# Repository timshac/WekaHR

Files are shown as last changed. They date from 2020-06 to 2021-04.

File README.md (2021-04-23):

# WekaHR modbus slave holding registers synchronised with google sheets

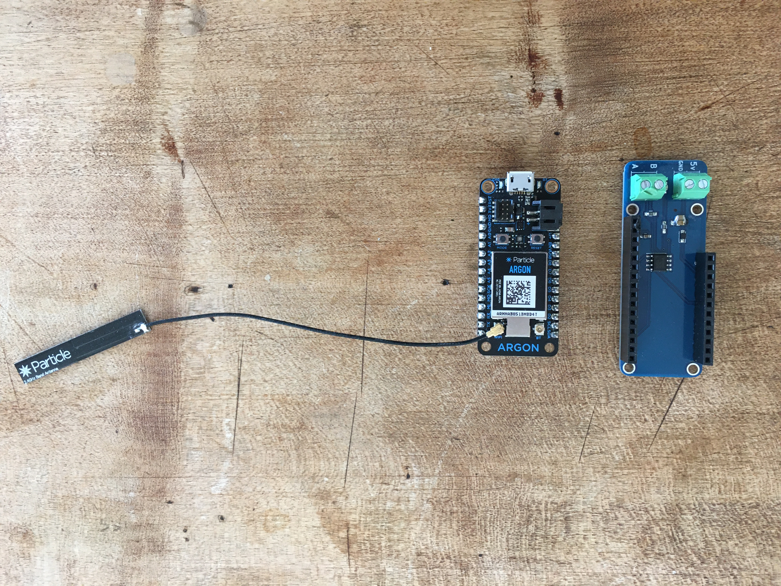
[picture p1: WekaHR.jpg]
WekaHR


The WekaHR is a modbus slave (RS-485) with read/write registers that are synced with your google sheet. Your PLC can connect to the WekaHR modbus slave to read and write register values to report data or configure PLC operations.

## Components

* WekaHR featherwing
* a PLC (supplied by you)
* Particle Argon (Wifi) or Boron (cellular) IOT device
* Google Sheet Application

## Connect hardware

1. Wire the WekaHR to your PLC.  The WekaHR is powered by 5v DC. Schnieder PLCs provide 5v via the modbus port
2. Insert the Boron or Argon into the WekaHR
3. Connnect particle Boron or Argon to the particle cloud, and give the device a name (deviceName)

Then you are ready to flash the firmware

## Flash Firmware

Clone this repository, and install the [particle command line tools](https://docs.particle.io/tutorials/developer-tools/cli/)

```
cd WekaHR/firmware/particle_gen3
# compile and flash over WiFi or Cellular
particle flash deviceName 

# or, for usb connected particle
particle compile argon|boron --saveTo=bin
particle serial list
particle serial flash bin
```

## Initial WekaHR module setup, for a fresh new module

Issue these commands to in the particle console (console.particle.io). The modbus baud is set in the code, currently to 19200 8N1
```
SetUnitID 10   # to set modbus slave ID (defaults to 10)
SetEventName "companyname/projectname"   # set the particle webhook event name

```

## Save a copy of the linked google sheet

Save a copy of this [WekaHR Google Sheets Template](https://docs.google.com/spreadsheets/d/1dsoAosavrSCt88q0tjWTA6WfT7lwxBgexuUGqGGjWAQ/copy?usp=sharing) and follow the instructions in the worksheet to connect your particle to the google sheet using a webhook.

## Connect particle cloud to google sheet

Follow the instructions in the google sheet to connect your particle device to the google sheeet using a particle webhook integration.

## Particle API - Functions

#### int ManualUpdate(String args = "")

Trigger a manual JSON packet publish and JSON settings register response.  Running this function ensures that application register values are set in the WekaHR.

#### int PublishUnitID(String args = "")

Publish the current modbus id. Defaults to 10.

#### int SetUnitID(String args = "number 1-247")

Set the device modbus id.

#### int PublishEventName(String args = "")

Publish the current event name.

#### int SetEventName(String args = "eventName")

Set the current event name.  Suggested format is CompanyName/ProjectName, where multiple customer sites may share the same CompanyName and ProjectName.

#### int PublishSettingsJSON(String args)

Publish the current JSON settings saved to EEPROM.  

#### int SetSettingsJSON(String args)

Save string args as current JSON settings to EEPROM.  Use with caution.

## JSON Published to Google Sheet

```
JSON:
{
  "name": "companyname/dairyshed",
  "data": "{\"v\":\"1.0\",\"func\":\"writeLog\",\"addr\":0,\"HR\":[0,0,0,0,0,0,0,0,0,0,0,0,0,0,0,0,0,0,2048,0,0,0,0,0,0,0,0,0,0,0,0,0,0,0,0,0,0,0,0,0,0,0,0,0,0,0,0,0,0,0,0,0,0,0,0,0,0,0,0,0,0,0,0,0,0,0,0,0,0,0,0,0,0,0,0,0,0,0,0,0]}",
  "ttl": 60,
  "published_at": "2019-10-20T01:54:46.580Z",
  "coreid": "coreid"
}

the data key, when interpreted as JSON:
{"v":"1.0","func":"writeLog","addr":0,"HR":[0,0,0,0,0,0,0,0,0,0,0,0,0,0,0,0,0,0,2048,0,0,0,0,0,0,0,0,0,0,0,0,0,0,0,0,0,0,0,0,0,0,0,0,0,0,0,0,0,0,0,0,0,0,0,0,0,0,0,0,0,0,0,0,0,0,0,0,0,0,0,0,0,0,0,0,0,0,0,0,0]}

```

Version "v" key, "v" = "1.0", where 1.0 could be anything < 2.0.  (eg 1.1,1.2, etc)
The holding registers are given as an array, starting at address "addr".
HR = [javascript array].  The current length of the array is 80 [registers addr + 0 to addr + 79], but could be anything from length 1-100.

The WekaHR accepts a JSON response that sets HR values.  The response looks like:

```

{"40":1,"41":2,"42":3,"43":0,"44":0,"45":0,"46":0,"47":0,"48":0,"49":0,"50":0,"51":0,"52":0,"53":0,"54":0,"55":0,"56":0,"57":0,"58":0,"59":0,"60":0,"61":0,"62":0,"63":0,"64":0,"65":0,"66":0,"67":0,"68":0,"69":0,"70":0,"71":0,"72":0,"73":0,"74":0,"75":0,"76":0,"77":0,"78":0,"79":12,"sheet":"https://docs.google.com/a/xxx.xxx.xxx/spreadsheets/d/yyyyyyyyyyyyyyyyyyyyyyyyyyyyyyyyyyyyyyyy/edit","row":38}

```

This includes registers set and their numeric value to be set, as well as the source google sheet or application url.

## Licenses

* Hardware: CERN-OHL-P
* Firmware: MIT
* Documentation: MIT

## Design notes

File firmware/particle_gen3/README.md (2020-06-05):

# WekaHR

 WekaHR Firmware

## Flash Firmware

This firmware can be used on a Particle.io Argon (wifi) or Boron (cellular) internet device.

Clone this repository, and install the [particle command line tools](https://docs.particle.io/tutorials/developer-tools/cli/)

```
cd WekaHR/firmware/particle_gen3
# compile and flash over WiFi or Cellular
particle flash deviceName 

# or, for usb connected particle
particle compile argon|boron --saveTo=bin
particle serial list
particle serial flash bin
```

## Save a copy of the linked google sheet

Save a copy of this [WekaHR Template](https://docs.google.com/spreadsheets/d/1dsoAosavrSCt88q0tjWTA6WfT7lwxBgexuUGqGGjWAQ/copy?usp=sharing) and follow the instructions in the worksheet to connect your particle to the google sheet using a webhook.

## API

### Functions

Call functions or read variables from the website front-end.  All functions take a string command argument and return an integer result.

Every time the WekaHR recieves an holding register (HR) write from the serial modbus, it publishes a JSON packet, and optionally accepts a JSON response from the application (google sheet) that will update any register values.

Modbus holdingh register reads read from Holding Registers on the slave device, and do not trigger a publish/response from the internet.

### Published Data

```
JSON:
{
  "name": "companyname/dairyshed",
  "data": "{\"v\":\"1.0\",\"func\":\"writeLog\",\"addr\":0,\"HR\":[0,0,0,0,0,0,0,0,0,0,0,0,0,0,0,0,0,0,2048,0,0,0,0,0,0,0,0,0,0,0,0,0,0,0,0,0,0,0,0,0,0,0,0,0,0,0,0,0,0,0,0,0,0,0,0,0,0,0,0,0,0,0,0,0,0,0,0,0,0,0,0,0,0,0,0,0,0,0,0,0]}",
  "ttl": 60,
  "published_at": "2019-10-20T01:54:46.580Z",
  "coreid": "coreid"
}

the data key, when interpreted as JSON:
{"v":"1.0","func":"writeLog","addr":0,"HR":[0,0,0,0,0,0,0,0,0,0,0,0,0,0,0,0,0,0,2048,0,0,0,0,0,0,0,0,0,0,0,0,0,0,0,0,0,0,0,0,0,0,0,0,0,0,0,0,0,0,0,0,0,0,0,0,0,0,0,0,0,0,0,0,0,0,0,0,0,0,0,0,0,0,0,0,0,0,0,0,0]}

```

Version "v" key, "v" = "1.0", where 1.0 could be anything < 2.0.  (eg 1.1,1.2, etc)
The holding registers are given as an array, starting at address "addr".
HR = [javascript array].  The current length of the array is 80 [registers addr + 0 to addr + 79], but could be anything from length 1-100.

The WekaHR accepts a JSON response that sets HR values.  The response looks like:

```

{"40":1,"41":2,"42":3,"43":0,"44":0,"45":0,"46":0,"47":0,"48":0,"49":0,"50":0,"51":0,"52":0,"53":0,"54":0,"55":0,"56":0,"57":0,"58":0,"59":0,"60":0,"61":0,"62":0,"63":0,"64":0,"65":0,"66":0,"67":0,"68":0,"69":0,"70":0,"71":0,"72":0,"73":0,"74":0,"75":0,"76":0,"77":0,"78":0,"79":12,"sheet":"https://docs.google.com/a/xxx.xxx.xxx/spreadsheets/d/yyyyyyyyyyyyyyyyyyyyyyyyyyyyyyyyyyyyyyyy/edit","row":38}

```

This includes registers set and their numeric value to be set, as well as the source google sheet or application url.

#### int ManualUpdate(String args = "")

Trigger a manual JSON packet publish and JSON settings register response.  Running this function ensures that application register values are set in the WekaHR.

#### int PublishUnitID(String args = "")

Publish the current modbus id. Defaults to 10.

#### int SetUnitID(String args = "number 1-247")

Set the device modbus id.

#### int PublishEventName(String args = "")

Publish the current event name.

#### int SetEventName(String args = "eventName")

Set the current event name.  Suggested format is CompanyName/ProjectName, where multiple customer sites may share the same CompanyName and ProjectName.

#### int PublishSettingsJSON(String args)

Publish the current JSON settings saved to EEPROM.  

#### int SetSettingsJSON(String args)

Save string args as current JSON settings to EEPROM.  Use with caution.

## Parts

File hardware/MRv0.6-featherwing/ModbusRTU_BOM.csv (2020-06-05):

Designator | MPN | Qty | Link
C1 | 0603B104K500NT | 1 | http://file.elecfans.com/web1/M00/7D/4D/o4YBAFwKKSOANZPCAA-X9Qix-h8480.pdf
C2 | CC0805KKX7R7BB106 | 1 | http://file.elecfans.com/web1/M00/65/A6/o4YBAFutoDWASZLJAA4wbrUogSs161.pdf
D1 | B0520WS-7-F | 1 | https://www.digikey.com/product-detail/en/diodes-incorporated/B0520WS-7-F/B0520WS-FDICT-ND/775881
D2 | ORH-YG36A | 1 | http://file.elecfans.com/web1/M00/87/3D/o4YBAFyCSiSATmSOAAZl20WJkbM116.pdf?filename=1536306275544842763.pdf
R1 | AC0603FR-07330RL | 1 | http://file.elecfans.com/web1/M00/81/15/o4YBAFwusm-AS-NzAA6jWBLJWvI829.pdf?filename=AC-series_Yageo.pdf
R2 | RC0603FR-07220RL | 1 | http://file.elecfans.com/web1/M00/9E/C4/pIYBAF053ayARjz1AAYrMQV5Kx0650.pdf
U2 | SP3485CN-L | 1 | https://www.digikey.com/product-detail/en/maxlinear-inc/SP3485CN-L/1016-1144-5-ND/2411076
J1, J2 | ED500/2DS | 2 | http://file.elecfans.com/web1/M00/9F/3B/pIYBAF1AhXyAEEsEAAqeTaLwtzM475.pdf
J3 | PPPC121LFBN-RC | 1 | https://www.digikey.com/product-detail/en/sullins-connector-solutions/PPTC121LFBN-RC/S6100-ND/807231
J4 | PPPC161LFBN-RC | 1 | https://www.digikey.com/product-detail/en/sullins-connector-solutions/PPTC161LFBN-RC/S7014-ND/810154

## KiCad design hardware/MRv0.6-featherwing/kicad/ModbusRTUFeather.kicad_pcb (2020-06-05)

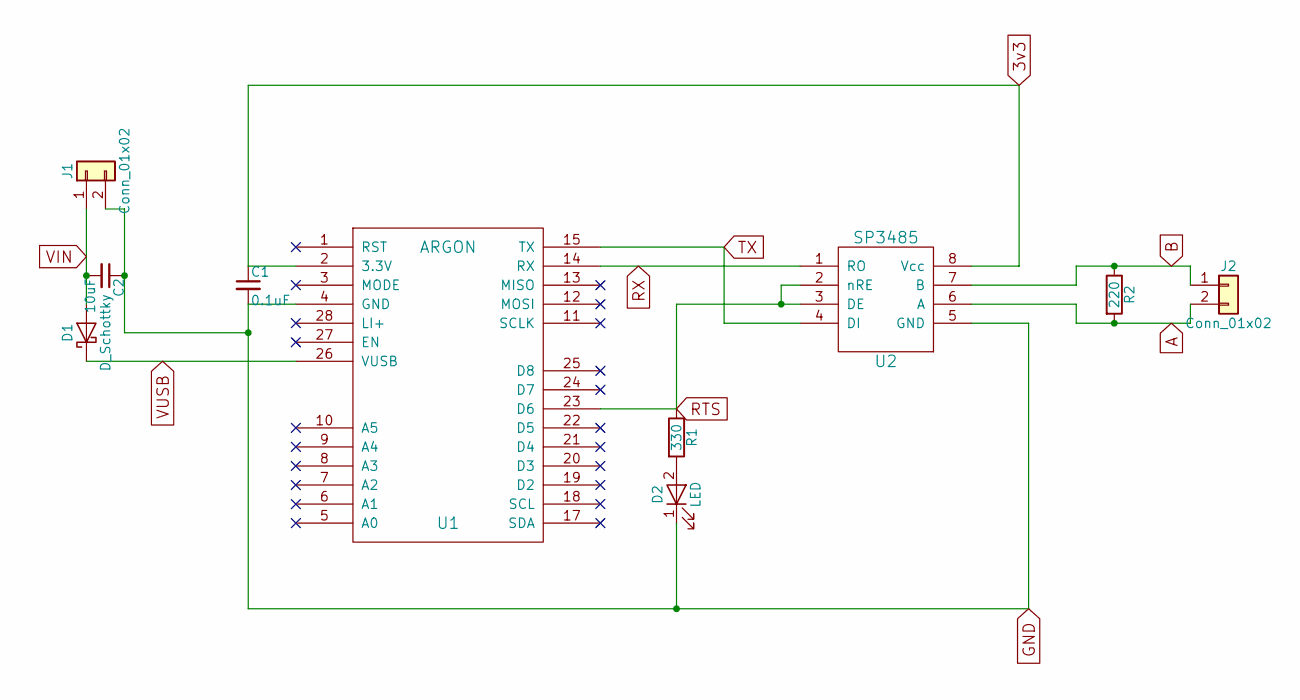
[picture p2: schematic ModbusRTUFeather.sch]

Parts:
C1: 0.1uF; C_0603_HandSoldering
C2: 10uF; C_0805_HandSoldering
D1: D_Schottky; D_SOD-323_HandSoldering
D2: LED; LED_0603_HandSoldering
J1, J2: Conn_01x02; TerminalBlock_Pheonix_PT-3.5mm_2pol
R1: 330; R_0603_HandSoldering
R2: 220; R_0603_HandSoldering
U1: ARGON; FeatherWing
U2: SP3485; SOIC-8_3.9x4.9mm_Pitch1.27mm

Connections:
3v3: C1.1, U1.2 (3.3V), U2.8 (Vcc)
A: J2.2, R2.2, U2.6 (A)
B: J2.1, R2.1, U2.7 (B)
GND: C1.2, C2.1, D2.1 (K), J1.2, U1.4 (GND), U2.5 (GND)
unnamed: D2.2 (A), R1.2
RTS: R1.1, U1.23 (D6), U2.2 (nRE), U2.3 (DE)
RX: U1.14 (RX), U2.1 (RO)
TX: U1.15 (TX), U2.4 (DI)
VIN: C2.2, D1.2 (A), J1.1
VUSB: D1.1 (K), U1.26 (VUSB)

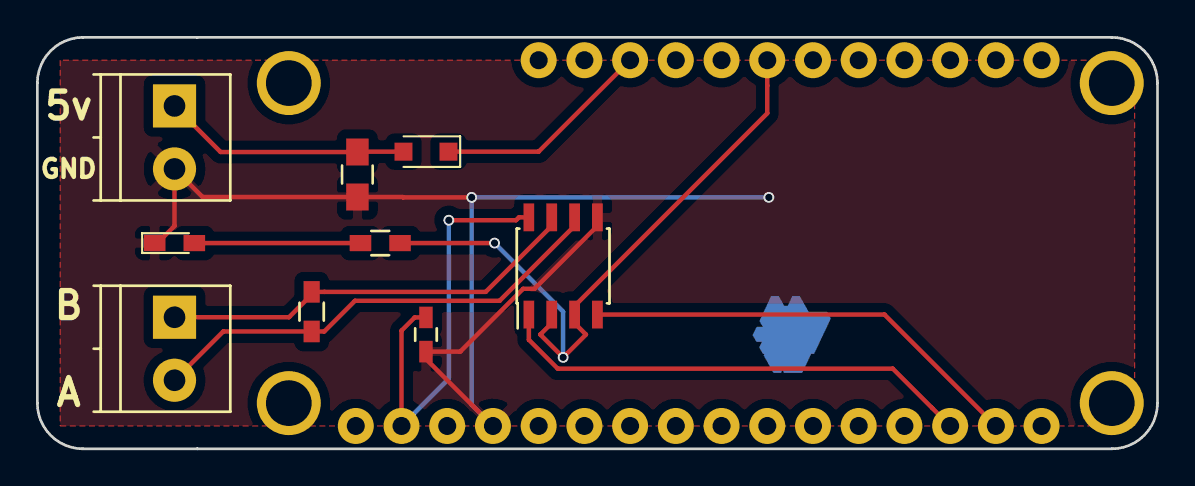
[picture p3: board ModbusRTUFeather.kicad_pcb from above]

Board: 2 copper layers, 62.2 x 22.9 mm, 12 parts (1 on the bottom side), 10 nets.

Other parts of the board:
PCB**: VAL**; PCB_FeatherWing_4hole
SHAClogo2: G***; SHAClogo2

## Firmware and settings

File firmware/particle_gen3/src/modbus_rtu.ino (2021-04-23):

/*
 * Project WekaHR
 * Description:  Sync modbus device registers with Google Sheets
 * Copyright (c) Hudson Sonoma LLC
 * License : MIT
 */

// This #include statement was automatically added by the Particle IDE.
#include "ModbusSlave.h"
#include <JsonParserGeneratorRK.h>
#include "print_json.h"

SYSTEM_THREAD(ENABLED);

SerialLogHandler logHandler;


/* slave id = 10, control-pin = D6, baud = 9600
 */
#define SLAVE_ID 10
#define CTRL_PIN D6
#define BAUDRATE 19200

#define PIN_MODE_INPUT 0
#define PIN_MODE_OUTPUT 1

/**
 *  Modbus object declaration.
 */
// TX and RX pins are Serial1
Modbus slave(Serial1,SLAVE_ID, CTRL_PIN);

JsonParserStatic<2048, 100> jsonParser;

// Watchdog
ApplicationWatchdog wd( 24 * 60 * 60 * 1000, System.reset);  // 60*1000 is 60 seconds.

#define HOLDING_REGISTERS_LENGTH 80
uint16_t HoldingRegisters[HOLDING_REGISTERS_LENGTH];

// timer MAIN LOOP
unsigned long previousMillis = 0;
static unsigned long TIMER = 2000;

// timer publish - quell publishes that are less than 1 second apart
unsigned long previousPublishMillis = 0;

//uint16_t slaveID = 10;
//String eventName = "modbus";

String configName = "WekaHR/settings";

class Weka_config {
public:
    int _magic_number;
    uint16_t _unitID;
    char _event_name[255];

    Weka_config(): _magic_number(12345), _unitID(10), _event_name("modbus") {}
    bool read_eeprom() {
        Weka_config a;
        EEPROM.get(1024, a);
        Log.info("eeprom: reading %d",a._magic_number);
        if (a._magic_number == _magic_number) {
            Log.info("eeprom: valid");
            _unitID = a._unitID;
            strncpy( _event_name, a._event_name, sizeof(_event_name) );
            return true;
        }
        Log.info("eeprom: invalid magic number");
        return false;
    }
    void save_eeprom() {
        EEPROM.put(1024, *this);
        Log.info("EEPROM write %s",_event_name);
    }
};

Weka_config wekaConfig;



void setup() {
  
   
    // RS485 control pin must be output
    pinMode(CTRL_PIN, OUTPUT);
    digitalWrite(OUTPUT, LOW);

    delay(1000);
    
    /* register handler functions.
     * into the modbus slave callback vector.
     */
    //slave.cbVector[CB_READ_COILS] = readDigital;
    //slave.cbVector[CB_READ_DISCRETE_INPUTS] = readDigital;
    //slave.cbVector[CB_WRITE_COILS] = writeDigitalOut;
    slave.cbVector[CB_READ_INPUT_REGISTERS] = ModbusReadHR;
    slave.cbVector[CB_READ_HOLDING_REGISTERS] = ModbusReadHR;
    slave.cbVector[CB_WRITE_HOLDING_REGISTERS] = ModbusWriteHR;

    // LOAD CONFIG STATE FROM EERPOM
    wekaConfig.read_eeprom();
    //slaveID = wekaConfig._unitID;
    //eventName = wekaConfig._event_name;

    // LOAD initial INPUT_REGISTER state from saved json.
    String saved_data = getEEPROMstring();
    Log.info("getEEPROMstring: %s", saved_data.c_str());
    JsonWriteHR("/", saved_data.c_str(), false);  // Call and do not save back to EEPROM.

    // be ready to accept new JSON responses
    // WEBHOOK: Must set Response Topic to be {{{PARTICLE_DEVICE_ID}}}/hook-response/{{{PARTICLE_EVENT_NAME}}}
    // What if multiple webhooks are configured and they all send back new config data? - Last setting is used.
    String event_name = System.deviceID() + String("/hook-response/") + String(wekaConfig._event_name);
    Particle.subscribe(event_name.c_str(), JsonWriteHRSubscribe, MY_DEVICES);
    Log.info("Particle.subscribe %s", event_name.c_str());

    // Particle Functions
    Particle.function("ManualUpdate",SyncNow);

    Particle.function("PublishUnitID",PublishUnitID);
    Particle.function("SetUnitID",WriteUnitID);

    Particle.function("PublishEventName",PublishEventName);
    Particle.function("SetEventName",WriteEventName);

    Particle.function("PublishSettingsJSON",PublishEEPROM_JSON);
    Particle.function("SetSettingsJSON",WriteEEPROM_JSON);

    // set Serial and slave at baud 9600. / 19200
    Serial1.begin(BAUDRATE,SERIAL_8N1);   //SERIAL_8N1
    //Serial.begin( BAUDRATE );
    slave.begin( BAUDRATE );
    slave.unitID = wekaConfig._unitID;

}

void WekaPublish(const char * event_name, String data) {
    Log.info(data);
    if (Particle.connected()) {
         Particle.publish(event_name, data, PRIVATE);
    } else {
        Log.info("NOT CONNECTED, DISCARDING");
    }
}

int PublishUnitID(String command) {
    String data = String::format("{\"unit_id\":%d}", slave.unitID);
    WekaPublish(configName.c_str(), data);
    return 1;
}
int WriteUnitID(String idString) {

    long id = idString.toInt();

    if ( id >= 1 && id <= 247 ) {
        wekaConfig._unitID = (uint16_t) id;
        slave.unitID = (uint16_t) id;
        wekaConfig.save_eeprom();

        PublishUnitID(idString);
        return 1;
    } else {
        return 0;
    }

}
int PublishEventName(String command) {
    String data = String::format("{\"event_name\":\"%s\"}", wekaConfig._event_name);
    WekaPublish(configName.c_str(), data);
    return 1;
}
int WriteEventName(String event_name) {

    if (event_name.length() < 255 && event_name.length() > 2 ) {
        strncpy ( wekaConfig._event_name, event_name.c_str(), event_name.length() );
        wekaConfig._event_name[event_name.length()] = 0;  // NULL terminate always

        Log.info("event_name: %s",wekaConfig._event_name);
        wekaConfig.save_eeprom();
        PublishEventName(event_name);
        return 1;
    } else {
        return 0;
    }

}





void loop() {
    /* listen for modbus commands con serial port.
     *
     * on a request, handle the request.
     * if the request has a user handler function registered in cbVector.
     * call the user handler function.
     */ 
    slave.poll();
    
    delay(100);   // a 10 0 0 0 1 2 0 65 15 4b a 10

    unsigned long currentMillis = millis();
    if(currentMillis - previousMillis > TIMER) {
        previousMillis = currentMillis;

        //Log.info("%s", "looped");
    }

}


/**
 * Handel Read Holding Registers 
 * write back the values from the Holding Registers.
 */
uint8_t ModbusReadHR(uint8_t fc, uint16_t address, uint16_t length) {
    // read analog input
    for (int i = 0; i < length; i++) {
        // write uint16_t value to the response buffer.
        if (address + i >= HOLDING_REGISTERS_LENGTH ) { return STATUS_ILLEGAL_DATA_ADDRESS; }
        slave.writeRegisterToBuffer(i, HoldingRegisters[address + i]);
    }
    
    //String data = String::format(
    //                "{ \"function\": \"%s\", \"fc\": %d, \"address\": %d, \"length\": %d }",
    //                "ModbusReadHR",fc,address,length);
    //Particle.publish("modbus", data, PRIVATE);
    
    Log.info("ModbusReadHR");

    return STATUS_OK;
}

/**
 * Handle Force Single Coil (FC=05) and Force Multiple Coils (FC=15)
 * set digital output pins (coils).
 */
uint8_t ModbusWriteHR(uint8_t fc, uint16_t address, uint16_t length) {

    // Copy data into HR
    for(int i=address;i<(address+length);i++) {
        if (i >= HOLDING_REGISTERS_LENGTH ) { return STATUS_ILLEGAL_DATA_ADDRESS; }
        HoldingRegisters[address + i] = slave.readRegisterFromBuffer(i);
    }

    return JsonReadHR("writeLog");
}

// Publish to JSON HR.  Max 622 characters. (or 565)
uint8_t JsonReadHR(const char *functionName) {

    String cols = "";
    for(int i=0;i<HOLDING_REGISTERS_LENGTH;i++) {
        cols += String::format("%d,",HoldingRegisters[i]);
    }    
    cols.remove(cols.length()-1); // remove last ", "
 

    // this means the first publish gets through.  SHould change this so the last publish, (after one second of quiet) gets through
    unsigned long currentMillis = millis();
    if(currentMillis - previousPublishMillis > 1000) {
        previousPublishMillis = currentMillis;

        String data = String::format(
                        "{\"v\":\"1.0\",\"func\":\"%s\",\"addr\":%d,\"HR\":[%s]}",
                        functionName,0,cols.c_str());
        WekaPublish(wekaConfig._event_name, data);

    } else {

        String data = String::format(
                        "{\"v\":\"1.0\",\"func\":\"%s\",\"addr\":%d,\"HR\":[%s]}",
                        functionName,0,cols.c_str());
        //Particle.publish("modbus", data, PRIVATE);

        Log.info("QUELLED - NOT PUBLISHED %s", functionName);
        Log.info("%s", data.c_str());

    }




    return STATUS_OK;

}

void JsonWriteHRSubscribe(const char *event, const char *data) {
    JsonWriteHR(event, data, true); // call and save to eeprom if needed

    wd.checkin(); // checkin on internet response.  If no response in 24hr, reboot.
}


// Subscribed JSON into HR
void JsonWriteHR(const char *event, const char *data, bool save2eeprom) {
    int responseIndex = 0;

    Log.info("%s", "JsonWriteHoldingRegisters");

    const char *slashOffset = strrchr(event, '/');
    if (slashOffset) {
        responseIndex = atoi(slashOffset + 1);
    }

    if (responseIndex == 0) {
        jsonParser.clear();
    }
    jsonParser.addString(data);

    if (jsonParser.parse()) {
        // Looks valid (we received all parts)

        // This printing thing is just for testing purposes, you should use the commands to
        // process data
        printJson(jsonParser);

        // SAVE TO ARRAY.
        // ASSUME JSON OBJECT OF THE FORMAT: {"0":1,"1":0,"2":3,"3":4,"4":5,"5":0,"6":0,"7":0,"8":0,"9":0,"10":0,"11":0,"12":0,"13":0,"14":0,"15":0,"16":0,"17":0,"18":0,"19":0,"20":0,"21":0,"22":0,"23":0,"24":0,"25":0,"26":0,"27":0,"28":0,"29":0,"30":0,"31":0,"32":0,"33":0,"34":0,"35":0,"36":0,"37":0,"38":0,"39":39}
        // where key < INPUT_REGISTERS_LENGTH.  Only registers named "0"-"39" are saved. others are ignored.
        char buf[3];
        bool registers_changed = false;
        for (int i = 0; i < HOLDING_REGISTERS_LENGTH; i++) {
            snprintf(buf,3,"%d",i);
            int intValue;
            if (jsonParser.getOuterValueByKey(buf, intValue)) {
                if (HoldingRegisters[i] != (uint16_t) intValue) {
                    HoldingRegisters[i] = (uint16_t) intValue;
                    Log.info("reg changed: %d", i );
                    registers_changed = true;
                }
            }

        }

        if (registers_changed) {
            if (save2eeprom) {
                Log.info("SAVE SETTINGS: %s", data);
                putEEPROMstring(data);
            }
        }   

    }
}



int SyncNow(String command) {

    return (int)JsonReadHR("SyncNow");

}

int PublishEEPROM_JSON(String command) {

    String saved_data;
    saved_data = getEEPROMstring();

    jsonParser.clear();
    jsonParser.addString(saved_data.c_str());
    if (jsonParser.parse()) {
        String ss = String::format("{\"eeprom\":%s}", saved_data.c_str() );
        WekaPublish(configName, ss);
    } else {
        String ss = String::format("{\"eeprom\": { } }");
        WekaPublish(configName, ss );
    }

    return 0;

}

int WriteEEPROM_JSON(String json) {

    jsonParser.clear();
    jsonParser.addString(json.c_str());
    if (jsonParser.parse()) {
        JsonWriteHR("/", json.c_str(), true);
        return 1;
    } else {
        return 0;
    }

}
 
// max 4096 chars
int putEEPROMstring(const char * data) {

    char buf[1024];
    if ( strlen(data) > 1024-1 ) { return -1; }
    strncpy ( buf, data, 1024 );
    buf[1024-1] = 0;  // NULL terminate always

    EEPROM.put(0, buf);

    return 0;

}

String getEEPROMstring() {

    char buf[1024];
    EEPROM.get(0,buf);
    return String(buf);

}

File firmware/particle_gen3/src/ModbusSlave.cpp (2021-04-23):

/**
 * Copyright (c) 2015, Yaacov Zamir <kobi.zamir@gmail.com>
 * Copyright (c) 2017, Andrew Voznytsa <andrew.voznytsa@gmail.com>, FC_WRITE_REGISTER and FC_WRITE_MULTIPLE_COILS support
 *
 * Permission to use, copy, modify, and/or distribute this software for any
 * purpose with or without fee is hereby granted, provided that the above
 * copyright notice and this permission notice appear in all copies.
 *
 * THE SOFTWARE IS PROVIDED "AS IS" AND THE AUTHOR DISCLAIMS ALL WARRANTIES
 * WITH REGARD TO THIS SOFTWARE INCLUDING ALL IMPLIED WARRANTIES OF
 * MERCHANTABILITY AND FITNESS. IN NO EVENT SHALL THE AUTHOR BE LIABLE FOR
 * ANY SPECIAL, DIRECT, INDIRECT, OR CONSEQUENTIAL DAMAGES OR ANY DAMAGES
 * WHATSOEVER RESULTING FROM LOSS OF USE, DATA OR PROFITS, WHETHER IN AN
 * ACTION OF CONTRACT, NEGLIGENCE OR OTHER TORTIOUS ACTION, ARISING OUT OF
 * OR IN CONNECTION WITH THE USE OR PERFORMANCE OF  THIS SOFTWARE.
 */

#include <assert.h>
#include <string.h>
#include "ModbusSlave.h"

/**
 * Init the modbus object.
 *
 * @param unitID the modbus slave id.
 * @param ctrlPin the digital out pin for RS485 read/write control.
 */
Modbus::Modbus(uint8_t _unitID, int _ctrlPin)
:Modbus(Serial, _unitID, _ctrlPin)
{}

/**
 * Init the modbus object.
 *
 * @param serial the serial port used for the modbus communication
 * @param unitID the modbus slave id.
 * @param ctrlPin the digital out pin for RS485 read/write control.
 */
Modbus::Modbus(Stream &_serial, uint8_t _unitID, int _ctrlPin)
:serial(_serial)
{
    // set modbus slave unit id
    unitID = _unitID;

    // set control pin for 485 write.
    ctrlPin = _ctrlPin;

    //Initialize variables
    timeout = 0;
    last_receive_time = 0;
    got_good_packet = false;
    lengthIn = 0;
}

/**
 * Begin serial port and set timeout.
 *
 * @param boud the serial port boud rate.
 */
void Modbus::begin(unsigned long baud) {
    // set control pin
    if (ctrlPin >= 0) {
        pinMode(ctrlPin, OUTPUT);
    }

    // set the timeout for 3.5 chars.
    serial.setTimeout(0);

    // set the T35 interframe timeout
    if (baud > 19200) {
        timeout = 1750;
    }
    else {
        timeout = 35000000 / baud; // 1T * 3.5 = T3.5
    }

    // init last received values
    last_receive_time = 0;
    lengthIn = 0;
}

/**
 * Calculate buffer CRC16
 *
 * @param buf the data buffer.
 * @param length the length of the buffer without CRC.
 *
 * @return the calculated CRC16.
 */
uint16_t Modbus::calcCRC(uint8_t *buf, int length) {
    int i, j;
    uint16_t crc = 0xFFFF;
    uint16_t tmp;

    // calculate crc16
    for (i = 0; i < length; i++) {
        crc = crc ^ buf[i];

        for (j = 0; j < 8; j++) {
            tmp = crc & 0x0001;
            crc = crc >> 1;
            if (tmp) {
              crc = crc ^ 0xA001;
            }
        }
    }

    return crc;
}

/**
 * wait for end of frame, parse request and answer it.
 */
int Modbus::poll() {
    int lengthOut = 0;
    uint16_t crc;
    uint16_t address;
    uint16_t length;
    uint16_t available_len;
    uint8_t fc;
    uint8_t cb_index;
    uint8_t cb_status;
    uint8_t error = STATUS_OK;

    /**
     * Read one data frame:
     */

    // check if we have data in buffer.
    available_len = serial.available( );
    if ( available_len > 0 ) {
        
        //delay(10);
        // old data is too old
        if ( micros( ) > ( last_receive_time + 2 * 1000 * 1000 ) || got_good_packet ) {  //   2 seconds
            lengthIn = 0;
        }
        got_good_packet = false;
        // we waited for the inter-frame timeout, read the frame.
        lengthIn += serial.readBytes( (char *) bufIn + lengthIn, 
                                      MAX_BUFFER - lengthIn );

        last_receive_time = micros( );
        delay(10);

        Log.info("MODBUS read bytes: %d", lengthIn);


       String data;
        for(int i=0;i<lengthIn;i++) {
            data += String(bufIn[i], HEX) + " ";
        }
        Log.info("%s\n",data.c_str());

    }
    else {
        return 0;
    }


    if (word(bufIn[lengthIn - 1], bufIn[lengthIn - 2]) == calcCRC(bufIn, lengthIn - 2) ) {  // if wire-crc == calc-crc

        String data;
        for(int i=0;i<lengthIn;i++) {
            data += String(bufIn[i], HEX) + " ";
        }
        //Log.info("%s\n",data.c_str());

        //Particle.publish("serial", data.c_str(), PRIVATE);
        Log.info("Serial: %s", data.c_str());
        
        // check unit-id
        Log.info("Unit: %d, fc: %d, address:%d, length:%d, wire-crc:%d, calc-crc:%d | lengthIn: %d", 
            bufIn[0],bufIn[1],word(bufIn[2], bufIn[3]), word(bufIn[4], bufIn[5]),
            word(bufIn[lengthIn - 1], bufIn[lengthIn - 2]), // wire-crc
            calcCRC(bufIn, lengthIn - 2), // calc-crc
            lengthIn);

        //Particle.publish("serial", String::format("fc: %d, address2: %d, length: %d",fc,address,length).c_str(), PRIVATE);

    } else {
        return 0;
    }

    //Log.info("Unit: %s\n",String(bufIn[0], HEX).c_str());

    if (bufIn[0] != unitID) return 0;
    
    //Particle.publish("serial", "unitID match", PRIVATE);
    
    //Particle.publish("serial", String::format("length: %d",lengthIn), PRIVATE);

    /**
     * Validate buffer.
     */
    // check minimum length.
    if (lengthIn < 8) return 0;

    
    /**
     * Get the Function code.
     */
    fc = bufIn[1];
    
    /**
     * Get message address and length/status.
     */
    address = word(bufIn[2], bufIn[3]); // first register.
    length = word(bufIn[4], bufIn[5]);  // number of registers to act upone or status.

    


    /**
     * Output length sanity check, and remove trailing noise from message.
     */
    switch (fc) {
        case FC_READ_COILS: // read coils (digital out state)
        case FC_READ_DISCRETE_INPUT: // read input state (digital in)
        case FC_READ_HOLDING_REGISTERS: // read holding registers (analog out state)
        case FC_READ_INPUT_REGISTERS: // read input registers (analog in)
            // sanity check.

            if (length > MAX_BUFFER) {
                error = STATUS_ILLEGAL_DATA_ADDRESS;
                // as long as I am not using gotos at all 
                // in case of protocol handling they are usefull for 
                // cleaning up when it comes to cleaning up
                // when something goes wrong while processing
                // instead og goto same can be implemented as nested
                // if statements
                goto respond;
            }

            // ignore tailing nulls.
            lengthIn = 8;

            break;
        case FC_WRITE_COIL:
            // ignore tailing nulls.
            lengthIn = 8;

            break;
        case FC_WRITE_REGISTER:

            // ignore tailing nulls.
            lengthIn = 8;

            break;
        case FC_WRITE_MULTIPLE_COILS:
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

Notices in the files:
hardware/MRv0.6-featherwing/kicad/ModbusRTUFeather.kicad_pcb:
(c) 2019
